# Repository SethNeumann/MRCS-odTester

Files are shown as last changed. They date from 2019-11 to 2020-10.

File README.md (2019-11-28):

# MRCS-odTester
## License: Creative Commons Attribution-NonCommercial-ShareAlike

A simple bench test board for Chubb\'s DCC-OD and MRCS\' cpOD detectors.

### Theory:

This board is designed to be a bench test unit for Chubb\'s DCCOD style
detectors. A board is inserted into the test pins and the three buttons
are pressed in sequence while observing the \"detected\" LED. A \"good\"
board will light up with both the \"low\" and \"normal\" button presses,
but not the \"high\" one. The DCCOD sensitivity can be adjusted in the
jig to give the desired behavior.

A local test track can be optionally connected that enables the testing
of specific locomotives and rolling stock simply by placing them on the
track.

The values for R1, R2 and R3 should be chosen for the layout and
locomotives in use - N-scale\'s small highly efficient motors will draw
less current than a O- or G-scale, and will require greater sensitivity.
Your wheelsets may provide 10K or 100K resistors, which should also
inform your choices. The values below are astarting point; feel free to
experiment. There is nothing wrong with choosing 100K as \"normal\" and
150K as \"too high\" as long as your choice of \"turns\" thru the
DCCOD\'s pulse transformer can provide the detection. Start with
\"normal\" matching your wheelset/rolling stock resistors, \"low\" being
half of that, and high being 2x to 10x of normal\...

Validate that your DCCOD can actually detect your chosen values by
adjusting its potentiometer to its mose sensitive position and observing
that the detected LED lights when the buttons are pressed.

Usage:

  -   Plug a DCCOD board to the DetectorTester.
  -   Connect to a 12v DC regulated power supply.
  -   Connect the output of a DCC booster to the DCC connector
  -   Press one of the pushbuttons to place a detectable load resistance across the simulated \"track\" for the detector to see
    -   Sensitivity test values (choose to match your givens and druthers)
    -   5K resistance (\~3mA)
    -   10K resistance (\~1.5mA)
    -   100K resistance (\~0.15mA)
    -   150K resistance (\~0.1mA)

Use the following table to diagnose/adjust based on the whether the
detection LED lights when the following buttons are pressed:

| LOW | NORMAL | HIGH  | |
|:----|:---|:---|:---|
| OFF | OFF | OFF | Nothing lights, missing DCCOD, no DCC power, no DC power, poorly chosen R1,R2 and R3|
|----
| OFF | OFF | ON | Bad detector tester - check solder connections|
|----
| OFF | ON | OFF | Bad detector tester - check solder connections|
|----
| OFF | ON | ON | Bad detector board - check solder connections|
|----
| ON  | OFF | OFF | this DCCOD will have problems detecting a typical car resistance. Adjust DCCOD until NORMAL lights when pressed|
|----
| ON  | OFF | ON | Bad detector tester - check solder connections|
|----
| ON  | ON | OFF | this DCCOD is properly adjusted|
|----
| ON  | ON | ON | this DCCOD is potentially overly sensitive, and may false trigger. Lower the DCCOD sensitivity until this just extinguishes|
|====

If any of the LEDs light when no buttons are pressed and nothing is connected to the external track connector, either the detector tester or the DCCOD is bad.

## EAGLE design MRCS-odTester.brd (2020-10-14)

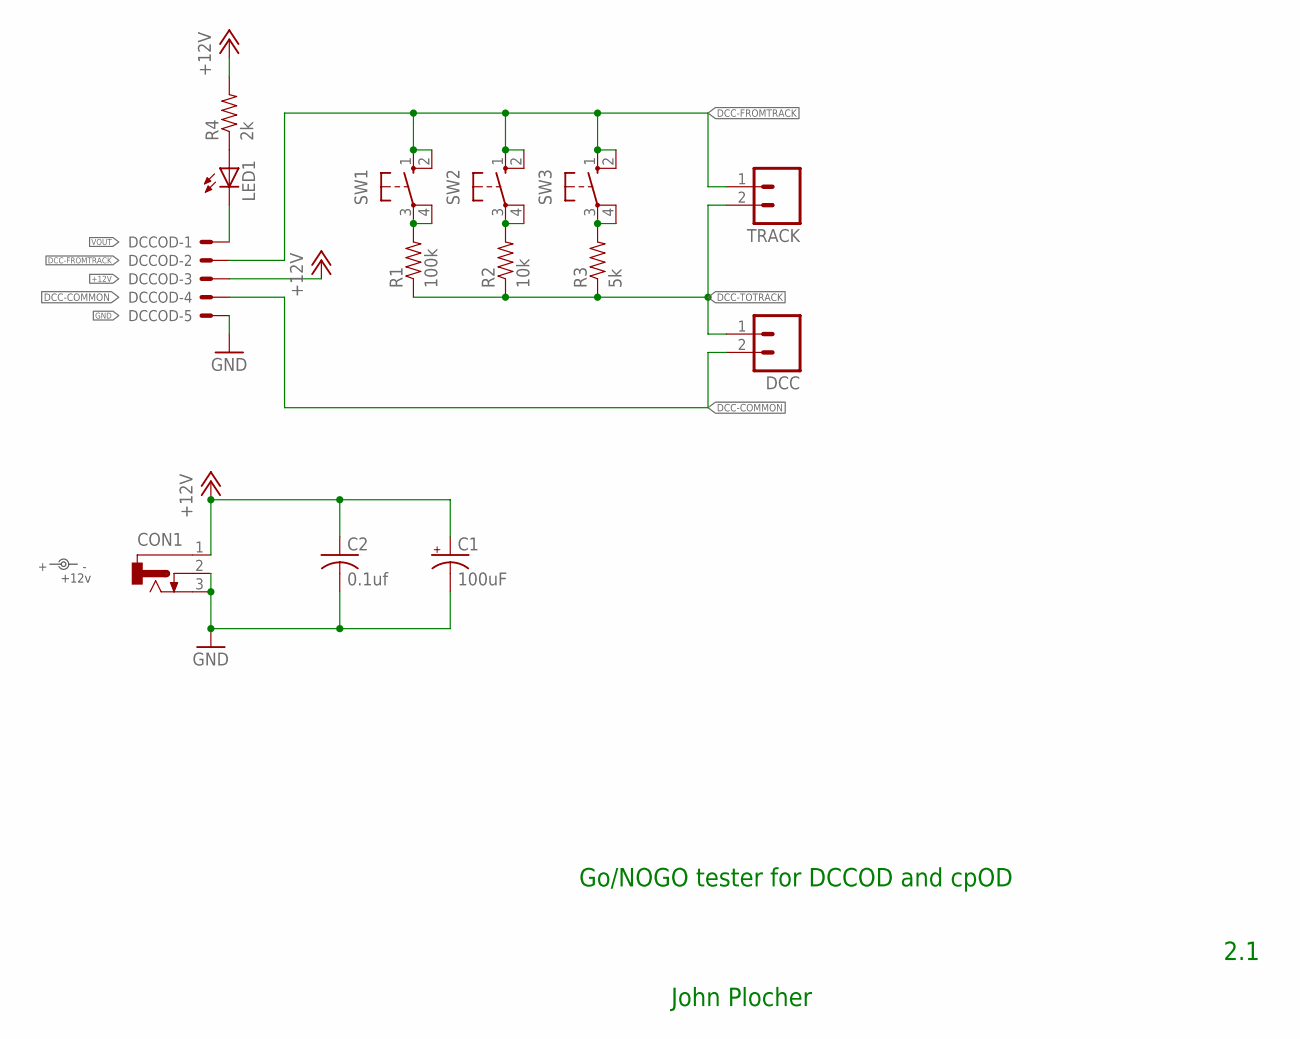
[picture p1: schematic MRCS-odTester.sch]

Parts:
C1: 100uF; E3.5-10
C2: 0.1uf; C050-024X044
CON1: CONNECTOR-DC-POWER-RA; DCJ0202
DCC: CONNECTOR-M02508-LOCK; MSTB2
DCCOD: KK-156-5
LED1: LEDLED5MM; LED5MM
R1: 100k; AXIAL-0.4-RES
R2: 10k; AXIAL-0.4-RES
R3: 5k; AXIAL-0.4-RES
R4: 2k; AXIAL-0.4-RES
SW1, SW2, SW3: SWITCH-10-XX; B3F-10XX
TRACK: CONNECTOR-M02508-LOCK; MSTB2
U$1: +12v; PWR_LABEL

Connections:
+12V: C1.+, C2.1, CON1.1, DCCOD.3, R4.P$2 (2)
DCC-COMMON: DCC.2 (B), DCCOD.4
DCC-FROMTRACK: DCCOD.2, SW1.1 (S), SW1.2 (S1), SW2.1 (S), SW2.2 (S1), SW3.1 (S), SW3.2 (S1), TRACK.1 (A)
DCC-TOTRACK: DCC.1 (A), R1.P$1 (1), R2.P$1 (1), R3.P$1 (1), TRACK.2 (B)
GND: C1.-, C2.2, CON1.2, CON1.3, DCCOD.5
unnamed: R1.P$2 (2), SW1.3, SW1.4 (P1)
unnamed: R2.P$2 (2), SW2.3, SW2.4 (P1)
unnamed: R3.P$2 (2), SW3.3, SW3.4 (P1)
unnamed: LED1.A, R4.P$1 (1)
VOUT: DCCOD.1, LED1.K (C)

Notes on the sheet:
Go/NOGO tester for DCCOD and cpOD
2.1
John Plocher

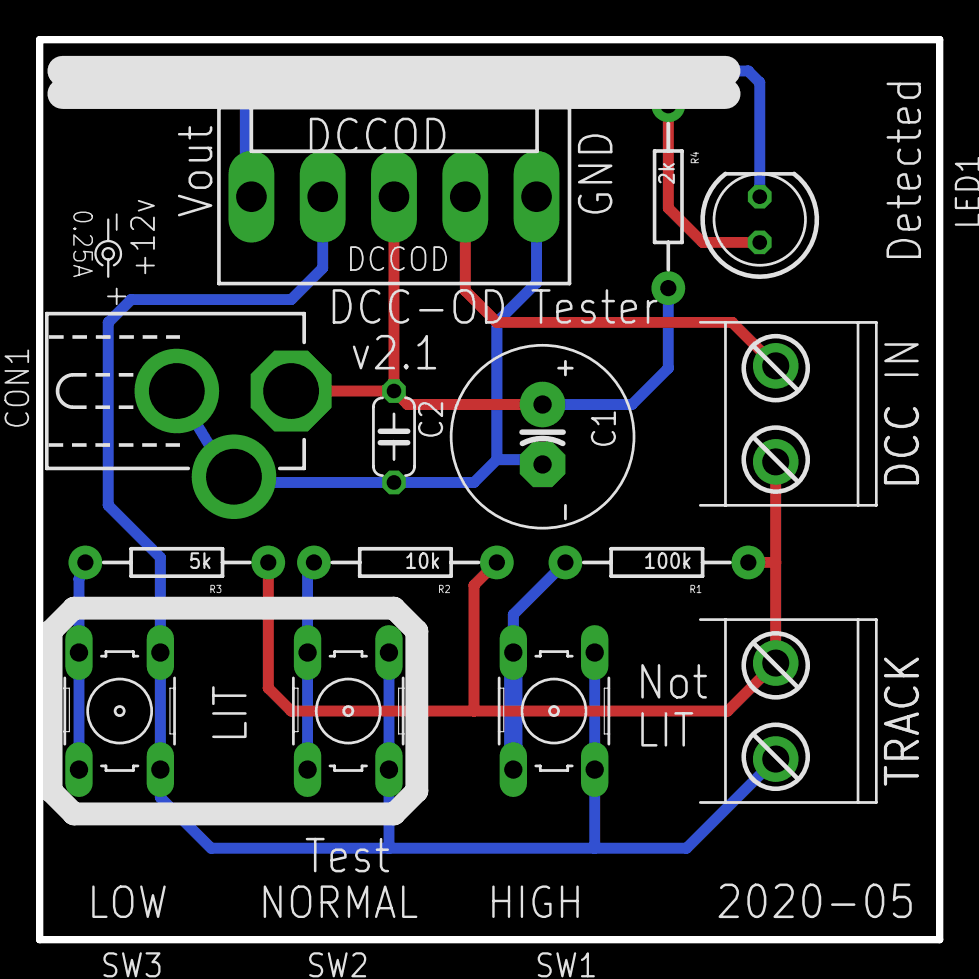
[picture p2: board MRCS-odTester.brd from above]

Board: 2 copper layers, 50.0 x 50.0 mm, 15 parts (0 on the bottom side), 10 nets.

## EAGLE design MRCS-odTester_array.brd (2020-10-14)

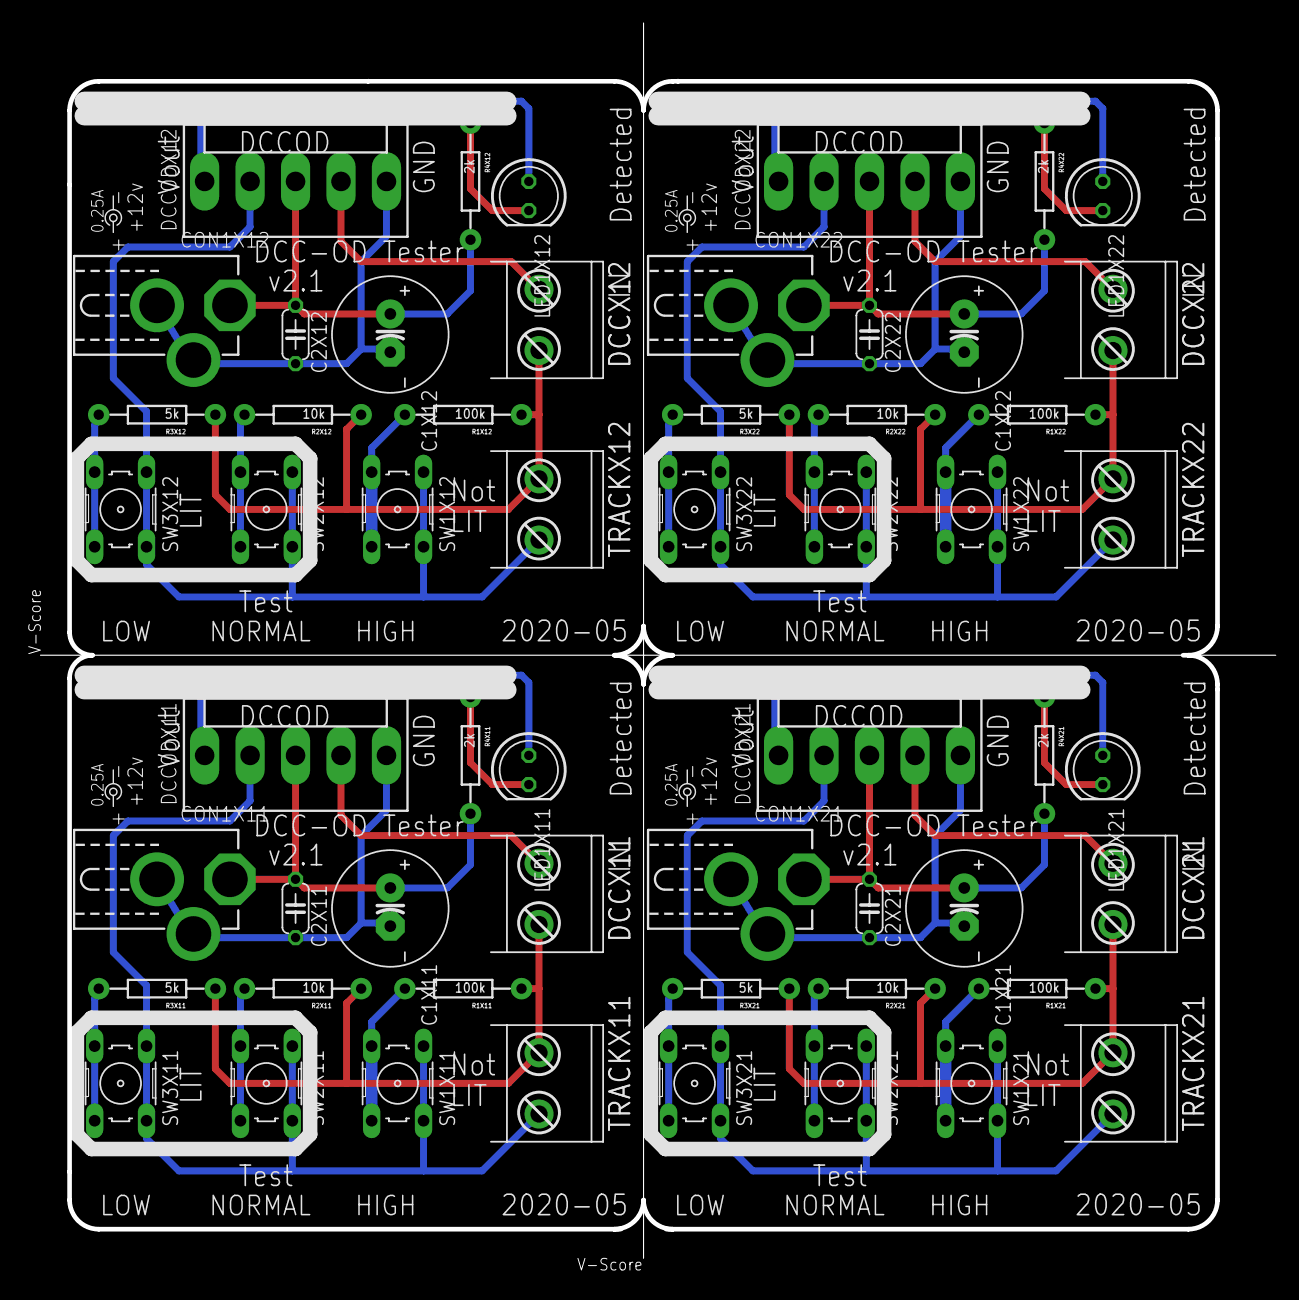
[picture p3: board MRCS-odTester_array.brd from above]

Board: 2 copper layers, 107.6 x 107.6 mm, 61 parts (0 on the bottom side), 40 nets.

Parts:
C1X11, C1X12, C1X21, C1X22: 100uF; E3.5-10
C2X11, C2X12, C2X21, C2X22: 0.1uf; C050-024X044
CON1X11, CON1X12, CON1X21, CON1X22: DCJ0202
DCCODX11, DCCODX12, DCCODX21, DCCODX22: KK-156-5
DCCX11, DCCX12, DCCX21, DCCX22: MSTB2
LED1X11, LED1X12, LED1X21, LED1X22: LED5MM
R1X11, R1X12, R1X21, R1X22: 100k; AXIAL-0.4-RES
R2X11, R2X12, R2X21, R2X22: 10k; AXIAL-0.4-RES
R3X11, R3X12, R3X21, R3X22: 5k; AXIAL-0.4-RES
R4X11, R4X12, R4X21, R4X22: 2k; AXIAL-0.4-RES
SW1X11, SW1X12, SW1X21, SW1X22, SW2X11, SW2X12, SW2X21, SW2X22, SW3X11, SW3X12, SW3X21, SW3X22: B3F-10XX
TRACKX11, TRACKX12, TRACKX21, TRACKX22: MSTB2
U$1X1: BOARD-10X10-2X2-PANEL-R
U$1X11, U$1X12, U$1X21, U$1X22: +12v; PWR_LABEL

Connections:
+12VX11: C1X11.+, C2X11.1, CON1X11.1, DCCODX11.3, R4X11.P$2
+12VX12: C1X12.+, C2X12.1, CON1X12.1, DCCODX12.3, R4X12.P$2
+12VX21: C1X21.+, C2X21.1, CON1X21.1, DCCODX21.3, R4X21.P$2
+12VX22: C1X22.+, C2X22.1, CON1X22.1, DCCODX22.3, R4X22.P$2
DCC-COMMONX11: DCCODX11.4, DCCX11.2
DCC-COMMONX12: DCCODX12.4, DCCX12.2
DCC-COMMONX21: DCCODX21.4, DCCX21.2
DCC-COMMONX22: DCCODX22.4, DCCX22.2
DCC-FROMTRACKX11: DCCODX11.2, SW1X11.1, SW1X11.2, SW2X11.1, SW2X11.2, SW3X11.1, SW3X11.2, TRACKX11.1
DCC-FROMTRACKX12: DCCODX12.2, SW1X12.1, SW1X12.2, SW2X12.1, SW2X12.2, SW3X12.1, SW3X12.2, TRACKX12.1
DCC-FROMTRACKX21: DCCODX21.2, SW1X21.1, SW1X21.2, SW2X21.1, SW2X21.2, SW3X21.1, SW3X21.2, TRACKX21.1
DCC-FROMTRACKX22: DCCODX22.2, SW1X22.1, SW1X22.2, SW2X22.1, SW2X22.2, SW3X22.1, SW3X22.2, TRACKX22.1
DCC-TOTRACKX11: DCCX11.1, R1X11.P$1, R2X11.P$1, R3X11.P$1, TRACKX11.2
DCC-TOTRACKX12: DCCX12.1, R1X12.P$1, R2X12.P$1, R3X12.P$1, TRACKX12.2
DCC-TOTRACKX21: DCCX21.1, R1X21.P$1, R2X21.P$1, R3X21.P$1, TRACKX21.2
DCC-TOTRACKX22: DCCX22.1, R1X22.P$1, R2X22.P$1, R3X22.P$1, TRACKX22.2
GNDX11: C1X11.-, C2X11.2, CON1X11.2, CON1X11.3, DCCODX11.5
GNDX12: C1X12.-, C2X12.2, CON1X12.2, CON1X12.3, DCCODX12.5
GNDX21: C1X21.-, C2X21.2, CON1X21.2, CON1X21.3, DCCODX21.5
GNDX22: C1X22.-, C2X22.2, CON1X22.2, CON1X22.3, DCCODX22.5
unnamed: R1X11.P$2, SW1X11.3, SW1X11.4
unnamed: R1X12.P$2, SW1X12.3, SW1X12.4
unnamed: R1X21.P$2, SW1X21.3, SW1X21.4
unnamed: R1X22.P$2, SW1X22.3, SW1X22.4
unnamed: R2X11.P$2, SW2X11.3, SW2X11.4
unnamed: R2X12.P$2, SW2X12.3, SW2X12.4
unnamed: R2X21.P$2, SW2X21.3, SW2X21.4
unnamed: R2X22.P$2, SW2X22.3, SW2X22.4
unnamed: R3X11.P$2, SW3X11.3, SW3X11.4
unnamed: R3X12.P$2, SW3X12.3, SW3X12.4
unnamed: R3X21.P$2, SW3X21.3, SW3X21.4
unnamed: R3X22.P$2, SW3X22.3, SW3X22.4
unnamed: LED1X11.A, R4X11.P$1
unnamed: LED1X12.A, R4X12.P$1
unnamed: LED1X21.A, R4X21.P$1
unnamed: LED1X22.A, R4X22.P$1
VOUTX11: DCCODX11.1, LED1X11.K
VOUTX12: DCCODX12.1, LED1X12.K
VOUTX21: DCCODX21.1, LED1X21.K
VOUTX22: DCCODX22.1, LED1X22.K

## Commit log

2020-05-04 silkscreen cleanup
    [MRCS-odTester.brd, MRCS-odTester.sch]
2020-10-14 created 2x2 panel
    [MRCS-odTester.brd, MRCS-odTester.sch, MRCS-odTester_array.brd]
